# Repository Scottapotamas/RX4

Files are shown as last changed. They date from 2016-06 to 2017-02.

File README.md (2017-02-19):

# RX4
Four receiver diversity board for 5.8Ghz video. Features onboard regulator, buzzer, oled and more. Should fit in a compact form factor.

I need to get the software working properly. I've tried to leave the source available where possible, though I haven't documented much of this as its a personal project.

# Progress so far

Some enclosure concepts have been drawn up.

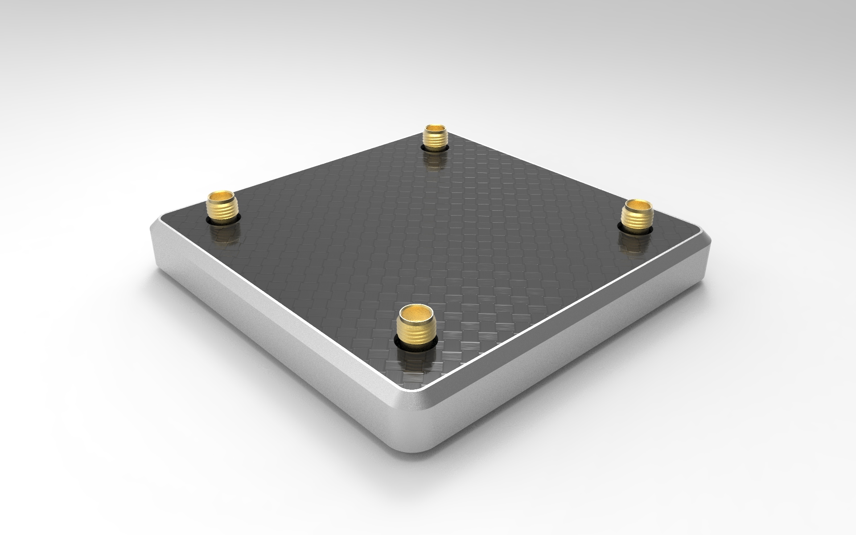
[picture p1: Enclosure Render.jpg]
Proposed Enclosure


The board has been made, and a basic level of validation done to show that everything works hardware wise.

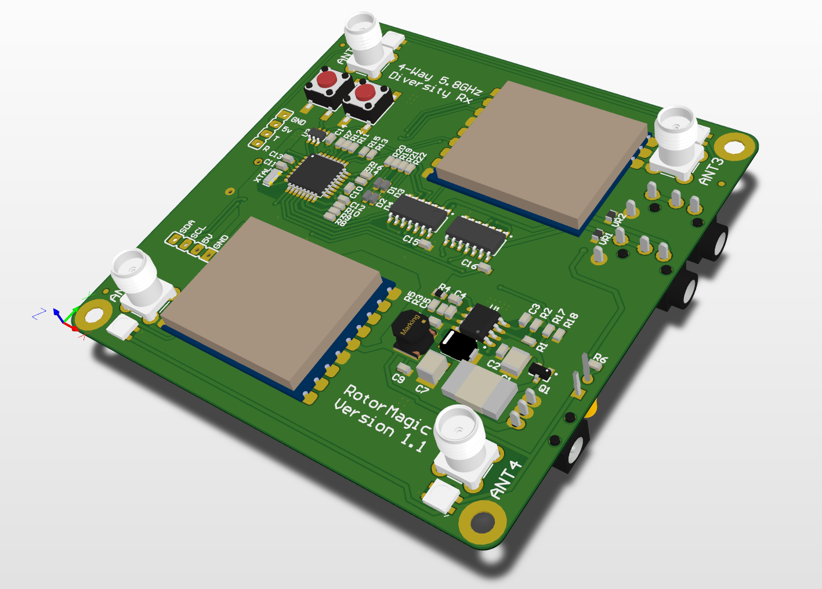
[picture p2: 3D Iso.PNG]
3D Iso View


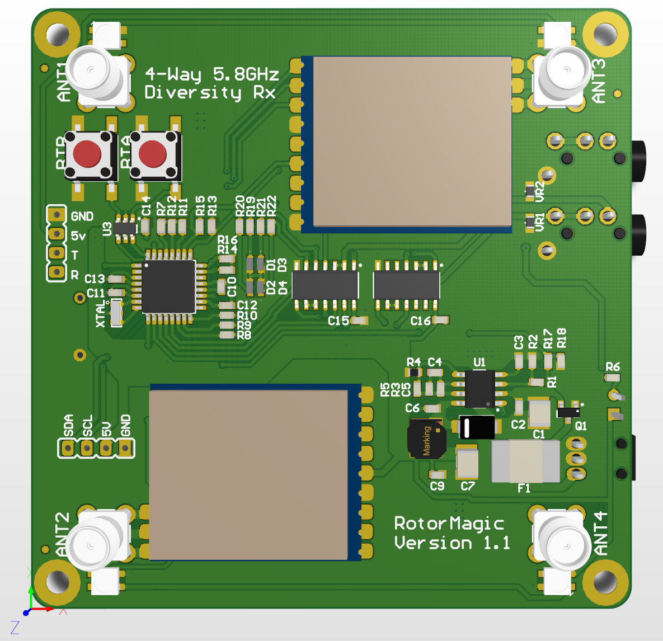
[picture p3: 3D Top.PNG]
3D Top View


The schematics and gerbers are all in this repo if anyone wants to borrow ideas for similar designs. There are other boards out there like the RX5800-Pro project and similar, but we use the TX5813 modules on this board due to native SPI support (no need to mod the 5800 internal resistors).

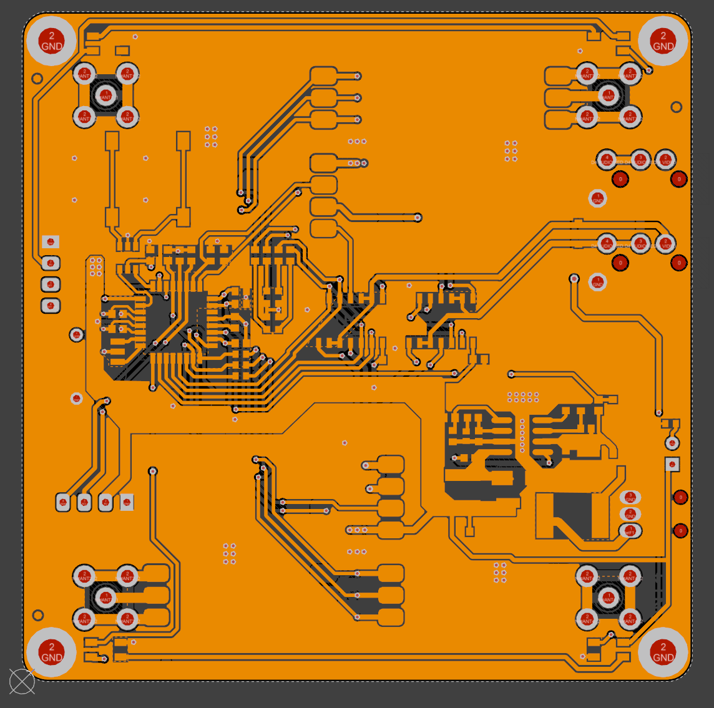
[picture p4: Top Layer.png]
Top Layer


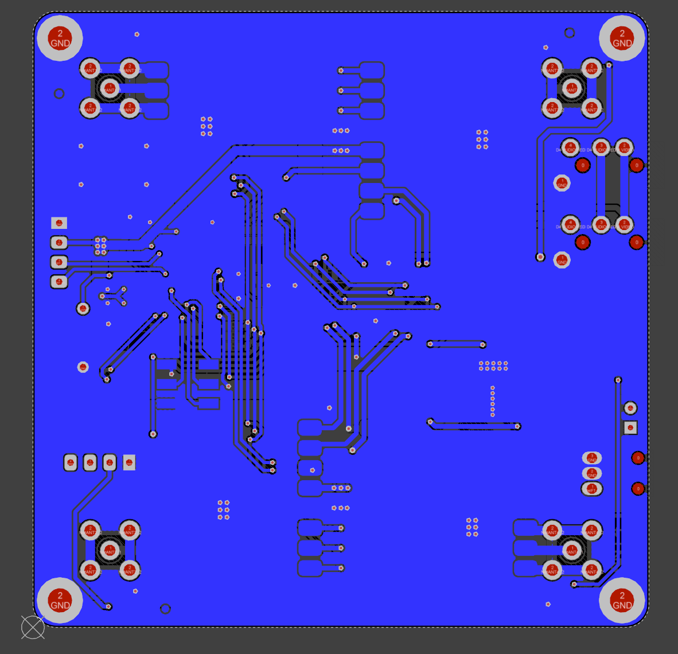
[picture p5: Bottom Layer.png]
Bottom Layer


The board is a simple 2-layer, 1oz design that fits inside a 80x80mm footprint. It should cost less than $40 to produce if you buy parts from Aliexpress/Banggood/Chinese sellers.

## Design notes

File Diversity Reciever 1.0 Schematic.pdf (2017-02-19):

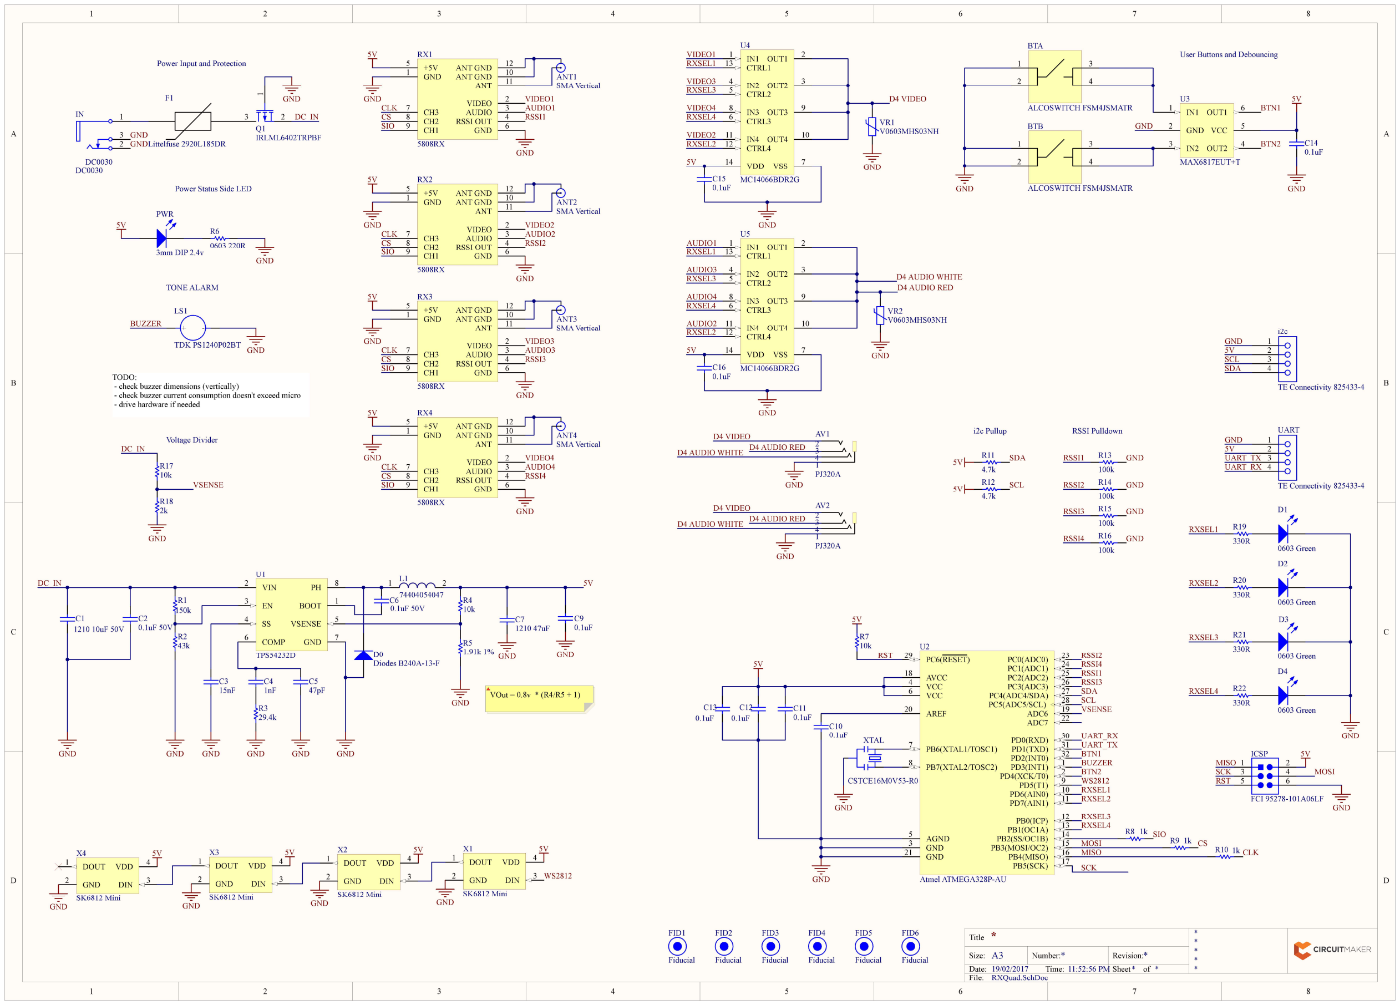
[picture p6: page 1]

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
* | *

*

* | *
19/02/2017 | 11:52:56 PM
RXQuad.SchDoc

Title

Size: | Number:
Date:
File:

Revision:
Time: | Sheet | of

A3

ANT1
SMA Vertical

ANT2
SMA Vertical

ANT3
SMA Vertical

ANT4
SMA Vertical

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
VIDEO1

VIDEO2

VIDEO3

VIDEO4

AUDIO1

AUDIO2

AUDIO3

AUDIO4

RSSI1

RSSI2

RSSI3

RSSI4

FID3

Fiducial

FID2

Fiducial

FID1

Fiducial

F1

Littelfuse 2920L185DR | 1
| 3 2 Q1 IRLML6402TRPBF

GND

DC_IN

1

2
3
4

AV1

PJ320A

1

2
3
4

AV2

PJ320A

GND

GND

D4 VIDEO

D4 VIDEO
D4 AUDIO RED

D4 AUDIO RED D4 AUDIO WHITE

D4 AUDIO WHITE

GND

GND

1

2

3

DC0030

IN

DC0030

PWR

3mm DIP 2.4v
GND
IN1 1 | OUT1 | 2
| OUT2 | 3

IN2 4
CTRL2 5

CTRL3 6

VSS | 7
IN3 8 | OUT3 | 9
OUT4 | 10 IN4 11
CTRL4 12

CTRL1 13

VDD 14

U4

MC14066BDR2G

IN1 1 | OUT1 | 2
| OUT2 | 3

IN2 4
CTRL2 5

CTRL3 6

VSS | 7
IN3 8 | OUT3 | 9
OUT4 | 10 IN4 11
CTRL4 12

CTRL1 13

VDD 14

U5

MC14066BDR2G

5V

5V

VIDEO1

VIDEO2

VIDEO4

AUDIO1

AUDIO3

AUDIO4

D4 VIDEO

D4 AUDIO RED

RXSEL1

RXSEL2

RXSEL4

RXSEL1

RXSEL2

RXSEL4

C16
0.1uF

GND

GND

VIDEO3

AUDIO2

RXSEL3

RXSEL3

+ -

LS1

TDK PS1240P02BT

PB5(SCK) 17

PB7(XTAL2/TOSC2) 8

PB6(XTAL1/TOSC1) 7

GND 3
GND 21

VCC 4
VCC 6

AGND 5

AREF 20

AVCC 18

PB4(MISO) | 16 PB3(MOSI/OC2) | 15 PB2(SS/OC1B) | 14 PB1(OC1A) | 13 PB0(ICP) | 12
PD7(AIN1) | 11 PD6(AIN0) | 10 PD5(T1) | 9
PD4(XCK/T0) | 2
PD3(INT1) | 1
PD2(INT0) | 32 PD1(TXD) | 31 PD0(RXD) | 30
ADC7 | 22 ADC6 | 19 PC5(ADC5/SCL) | 28 PC4(ADC4/SDA) | 27 PC3(ADC3) | 26 PC2(ADC2) | 25 PC1(ADC1) | 24 PC0(ADC0) | 23 PC6(RESET) 29

U2

Atmel ATMEGA328P-AU

RSSI1

RSSI2

RSSI3

RSSI4

R8 1k
R9 1k
R10 1k

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
4.7k
R12
4.7k

5V

5V

RSSI1

RSSI2

RSSI3

RSSI4

R13
100k
R14
100k
R15
100k
R16
100k

GND

GND

GND

GND

i2c Pullup | RSSI Pulldown

DC_IN

VSENSE

R17
10k

R18
2k

GND

Voltage Divider

VSENSE

UART_TX

UART_RX

RXSEL1
RXSEL2

RXSEL3
RXSEL4

BUZZER

TONE ALARM

5V

Power Status Side LED

Power Input and Protection

FID5

Fiducial

FID4

Fiducial

FID6

Fiducial

BTN1

BTN1

BTN2

XTAL

CSTCE16M0V53-R0

GND

IN1 1

GND 2

IN2 3 | OUT2

4

VCC

5

OUT1

6

U3

MAX6817EUT+T

5V

GND

C14
0.1uF
GND | GND

User Buttons and Debouncing

GND

TODO:
- check buzzer dimensions (vertically)
- check buzzer current consumption doesn't exceed micro
- drive hardware if needed

BUZZER

BTN2 | 3 1 2

6

4
5

ICSP

FCI 95278-101A06LF
GND

RST

SCK

MISO
MOSI

5V

RST

MISO

MOSI

SCK

R7
10k

5V

C10
0.1uF

GND

5V

BOOT 1

VIN 2

EN 3

SS 4 | VSENSE | 5
COMP 6 | GND | 7
| PH | 8

U1

TPS54232D

C2
0.1uF 50V

GND

R1
150k

C3
15nF

GND

C4
1nF

C5
47pF

R3
29.4k
GND | GND

C6
0.1uF 50V

GND

R4
10k

GND

GND | GND

D0
Diodes B240A-13-F

1 2 L1

74404054047

5V

D4 AUDIO WHITE

R6
0603 220R

DC_IN

C11
0.1uF

C12
0.1uF

VR1
V0603MHS03NH

VR2
V0603MHS03NH

GND

5V

WS2812

5V | 5V 5V

1
2
3
4

i2c

TE Connectivity 825433-4

1
2
3
4

UART

TE Connectivity 825433-4

GND
5V
UART_TX
UART_RX

GND
5V
SCL
SDA

C13
0.1uF

1 3

2 4

BTA

ALCOSWITCH FSM4JSMATR

1 3

2 4

BTB

ALCOSWITCH FSM4JSMATR

GND 1

VIDEO | 2
AUDIO | 3
RSSI OUT | 4

+5V 5

GND 6

CH3 7
CH2 8
CH1 9
ANT GND | 10
ANT | 11
ANT GND | 12

RX1

5808RX

GND 1

VIDEO | 2
AUDIO | 3
RSSI OUT | 4

+5V 5

GND 6

CH3 7
CH2 8
CH1 9
ANT GND | 10
ANT | 11
ANT GND | 12

RX2

5808RX

GND 1

VIDEO | 2
AUDIO | 3
RSSI OUT | 4

+5V 5

GND 6

CH3 7
CH2 8
CH1 9
ANT GND | 10
ANT | 11
ANT GND | 12

RX3

5808RX

GND 1

VIDEO | 2
AUDIO | 3
RSSI OUT | 4

+5V 5

GND 6

CH3 7
CH2 8
CH1 9
ANT GND | 10
ANT | 11
ANT GND | 12

RX4

5808RX
D1

0603 Green
D2

0603 Green

D3

0603 Green
D4

0603 Green

R19
330R

R20
330R

R21
330R

R22
330R

RXSEL1

RXSEL2

RXSEL3

RXSEL4

GND

C7
1210 47uF

C9
0.1uF

GND

R2
43k

C1
1210 10uF 50V
R5
1.91k 1%

WS2812

GND

C15
0.1uF
DIN | 3
VDD | 4 DOUT 1

GND 2

X1

SK6812 Mini

DIN | 3
VDD | 4 DOUT 1

GND 2

X2

SK6812 Mini

DIN | 3
VDD | 4 DOUT 1

GND 2

X3

SK6812 Mini

DIN | 3
VDD | 4 DOUT 1

GND 2

X4

SK6812 Mini
GND | GND | GND | GND

VOut = 0.8v * (R4/R5 + 1)

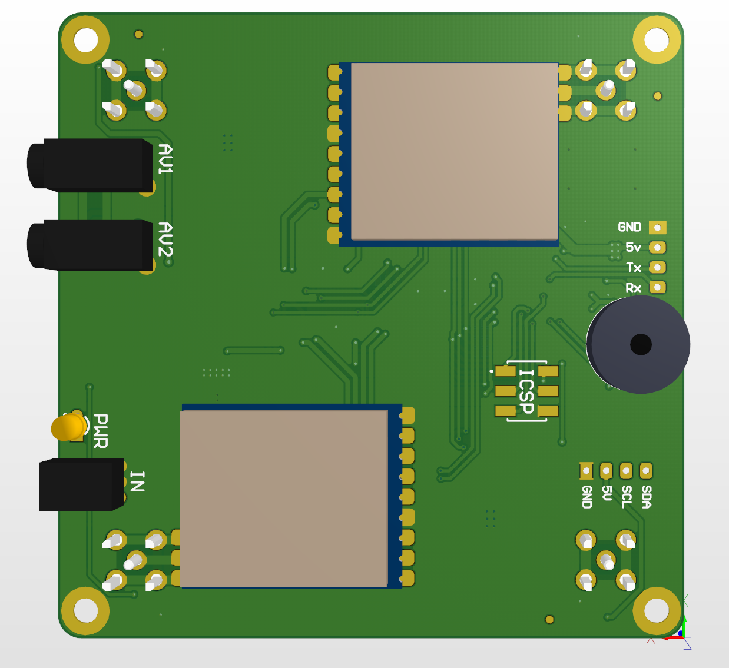
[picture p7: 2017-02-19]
3D Bottom.PNG

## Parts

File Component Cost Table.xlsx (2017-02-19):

 | 4 Way Diversity Board |  |  | Single Board Part Cost (in qty 10)
RS Item Number | QTY | Name | Description | Price | Summed Cost | Link | Link 2
616-3422 | 4 | SMA Vertical | SMA vertical, 4-pinG connector (J34 on ali) | 0.35 | 1.4 | http://www.aliexpress.com/item/Free-Shipping-10pcs-lot-PCB-Mount-SMA-Female-Plug-Straight-Receptacle-Solder-Adapter-Connector/1922491056.html | http://au.rs-online.com/web/p/sma-connectors/6163422/
703-1149 | 1 | 3mm White LED | Power Status LED | 0.1 | 0.1 | http://www.aliexpress.com/item/50pcs-3mm-Flat-Top-LED-LAMP-White-Super-brgiht-Wide-Angle-Light-Transparent-Light-Emitting-Diode/32618888645.html
732-6841 | 1 | MAX6817EUT | Switch Debouncer Circuit | 3.1 | 3.1 | http://www.aliexpress.com/item/Free-shipping-5pcs-lot-MAX6817EUT-MAX6817-interface-chip-SOT-23-6-new-original/32594672709.html
780-0712 | 1 | 12mm 5V buzzer | Warning Alert and Tones | 0.74 | 0.74 | http://www.aliexpress.com/item/Free-shipping-12x6-5-5V-buzzer-active-electromagnetic-YMD12065-10pcs/32302608810.html
479-1508 | 2 | 6x6x6 Tactile Button | Menu buttons | 0.15 | 0.3 | http://www.aliexpress.com/item/Free-shipping-10pcs-4pin-SMD-6-6-6mm-for-Tact-Switch-Push-Button-Tactile-Pushbutton-LCD/32374729164.html
 | 1 | WQP-DC0030 | 3.5x1.3mm DC Socket | 0.19 | 0.19 | http://www.aliexpress.com/item/10-Pcs-Black-3-Pin-3-5mm-x-1-3mm-DC-Power-Jack-Socket-PCB-Mount/32526176898.html | http://www.qingpu-electronics.com/en/products/WQP-DC0030-42.html
 | 2 | WQP-PJ320A | 3.5mm AV 4 pole socket | 0.22 | 0.44 | http://www.aliexpress.com/item/20PCS-LOT-PJ320A-pj320a-PJ-320A-pj-320a-100-New-Original-Package/32639808990.html | http://www.qingpu-electronics.com/en/products/WQP-PJ320A-175.html
 | 1 | 0.91" OLED | On pcb already, 128x32px | 5.4 | 5.4 | http://www.aliexpress.com/item/0-91-OLED-display-module-128-x-32-px-resolution-white-characters-in-black-background-14/32629988003.html
 | 4 | RX5808 Module | 5.8Ghz module | 12 | 48 | http://www.aliexpress.com/item/FPV-Boscam-FPV-5-8G-Wireless-Audio-Video-Receiving-Module-RX5808-free-shipping/32557296513.html | http://www.banggood.com/FPV-5_8G-Wireless-Audio-Video-Receiving-Module-RX5808-p-84775.html
169-7790 | 2 | 74HC4066D SOIC14 | 4x SPST digital switch | 0.71 | 1.42 | http://au.rs-online.com/web/p/products/1697790/
760-6826 | 4 | V0603MHS03NH | MOV/Varistor 6pF 1A 135V 0603 | 0.33 | 1.32 | https://au.rs-online.com/web/p/products/7606826/?sra=p&r=t#
619-7740 | 1 | NCP18XH103J03RB | 10k 0603 Thermistor | 0.1 | 0.1 | http://www.aliexpress.com/item/Free-Shipping-50PCS-LOT-0603-SMD-Thermistor-Thermal-Resistor-5-10K-B-Value-3450K-3-25/32390676031.html | http://au.rs-online.com/web/p/thermistors/6197740/?searchTerm=0603+10k+thermistor
696-3092 | 1 | ATMEGA328P-AU | Microcontroller | 5.61 | 5.61 | http://au.rs-online.com/web/p/products/6963092/
700-9975 | 1 | B240A | Power Supply Diode | 0.32 | 0.32 | http://au.rs-online.com/web/p/products/7009975/?sra=p&r=t
792-6524 | 1 | CSTCE16M0V53-R0 | 16Mhz Resonator | 0.336 | 0.336 | http://au.rs-online.com/web/p/ceramic-resonators/7926524/
301-322 | 1 | IRLML6402TRPBF | P-Fet as ideal diode | 0.75 | 0.75 | http://au.rs-online.com/web/p/mosfet-transistors/0301322/
895-1640 | 1 | 2920L200DR | 2A Polyfuse | 1.03 | 1.03 | http://au.rs-online.com/web/p/resettable-surface-mount-fuses/8951640/
 | 4 | SK6812 MINI | RGB LEDs for status lights | 0.55 | 2.2 | https://www.adafruit.com/products/2659 | http://www.aliexpress.com/item/SMD3535-Beads-smart-led-mini-led-SK6812MINI-SK6812-adressable-full-color-RGB-3535-LED-light-source/32425415556.html
698-9085 | 1 | TPS54232D | SMPS regulator | 2.91 | 2.91 | http://au.rs-online.com/web/p/buck-converters/6989085/?searchTerm=TPS54232D
814-2559 | 1 | 74404054047 | 4.7uH 3A Inductor | 1 | 1 | http://au.rs-online.com/web/p/wire-wound-surface-mount-inductors/8142559/
 | 14 | 0603 Capacitors | Assorted, Ceramic, X7R | 0.05 | 0.7
 | 19 | 0603 Resistors | Assorted, 5%, 1/8W | 0.01 | 0.19
MTO | 1 | PCB 80x80mm | 2 layer, 1oz | 2 | 2 | http://www.elecrow.com/10pcs-2-layer-pcb-p-1175.html
 |  |  |  | Total Cost | 79.556

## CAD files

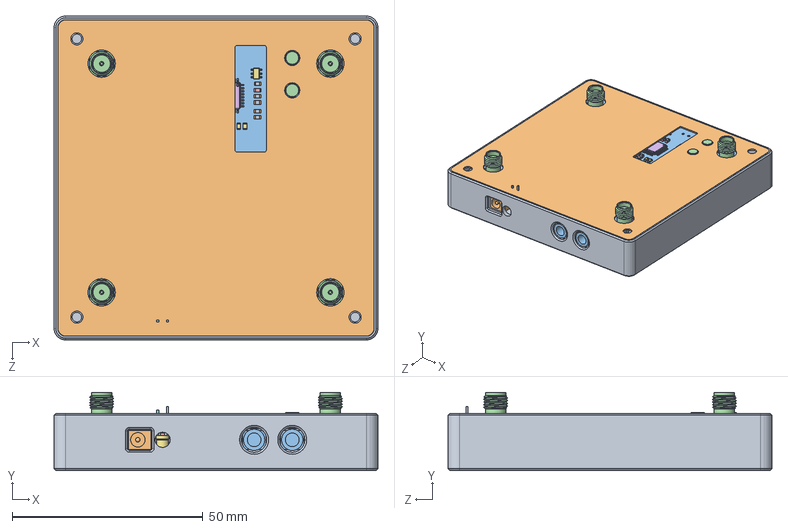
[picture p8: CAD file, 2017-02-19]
CAD/Enclosure Mockup/Prototype Enclosure 1.SLDASM
85.0 x 20.5 x 85.0 mm
Alu enclosure
Lid
Board
Extruded x 3
Extruded_2 x 6
V0603MHS03NH_Varistor x 4
Extruded_3
Extruded_4
Extruded_5 x 4
Extruded_6 x 8
Extruded_7 x 4
Extruded_8 x 8
User_Library-LA_3366_sc_BODY_amber
User_Library-LA_3366_sc_LEAD_A_sc
User_Library-LA_3366_sc_LEAD_K_sc
DC0030
PJ320A x 2
c-5-1814832-1-b-3d x 4
RX5808 x 4
Extruded_9 x 2
Extruded_10
User_Library-SOT23-3
Extruded_11 x 8
Extruded_12 x 4
Extruded_13 x 8
Extruded_14 x 4
Diode_SMA
S2B-PH-K-S
housing
contact x 2
spule
Glue
Extruded_15
Extruded_16 x 2
Extruded_17 x 3
Extruded_18 x 6
Extruded_19 x 6
Extruded_20 x 12
Extruded_21 x 5
Extruded_22 x 10
Extruded_23
Extruded_24 x 2
TQFP32-08
BODY_MF06A
LEAD_MF06A x 6
BODY_M14A_20 x 2
LEAD_M14A_46 x 28
SK6812Mini x 4
X3-SMD-3.6X1.3X0.8MM

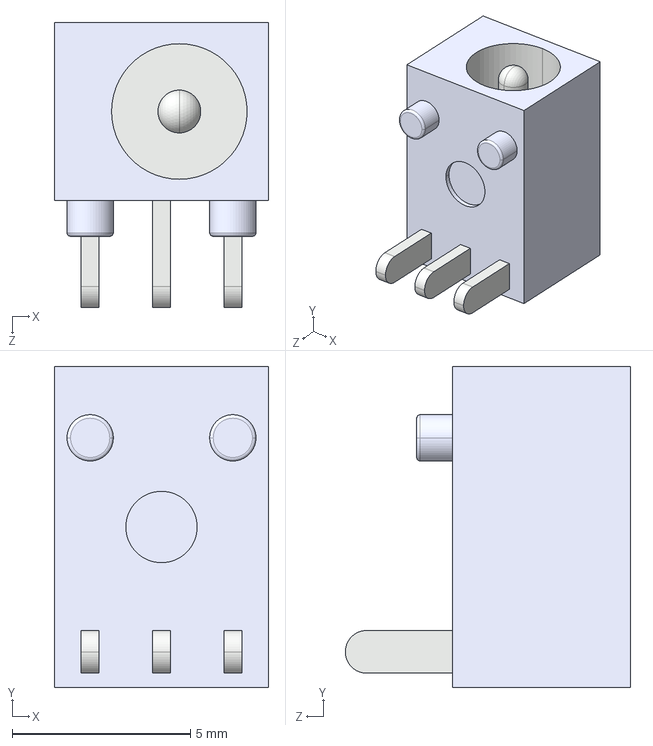
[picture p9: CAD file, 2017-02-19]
CAD/Connectors/DC0030.STEP
6.00 x 9.00 x 8.00 mm

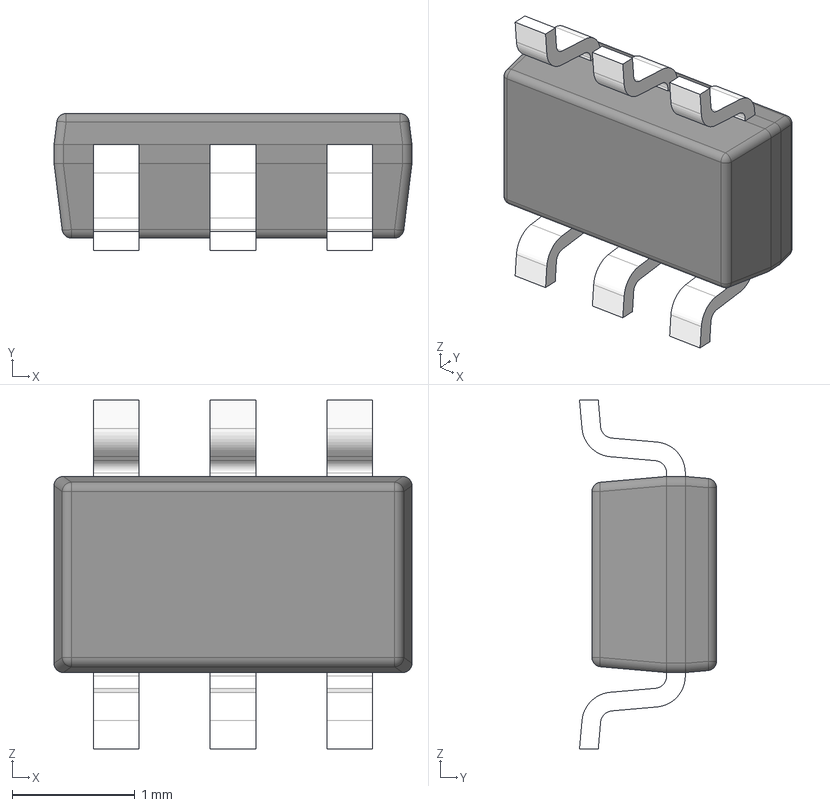
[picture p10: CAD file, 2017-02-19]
CAD/ICs/sot-23-6.stp
2.92 x 1.12 x 2.84 mm
BODY_MF06A
LEAD_MF06A x 6

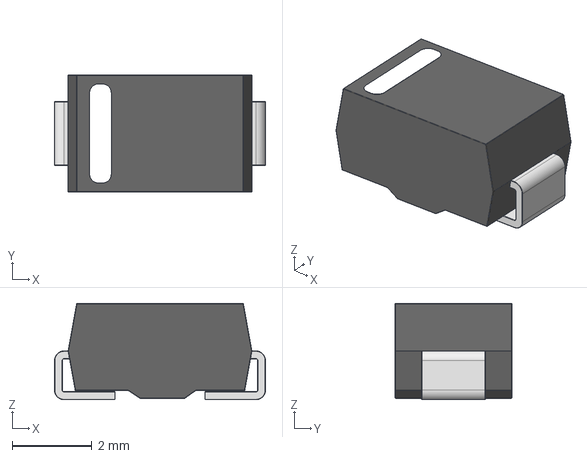
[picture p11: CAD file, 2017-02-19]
CAD/Other/Diode SMA.stp
5.28 x 2.92 x 2.41 mm

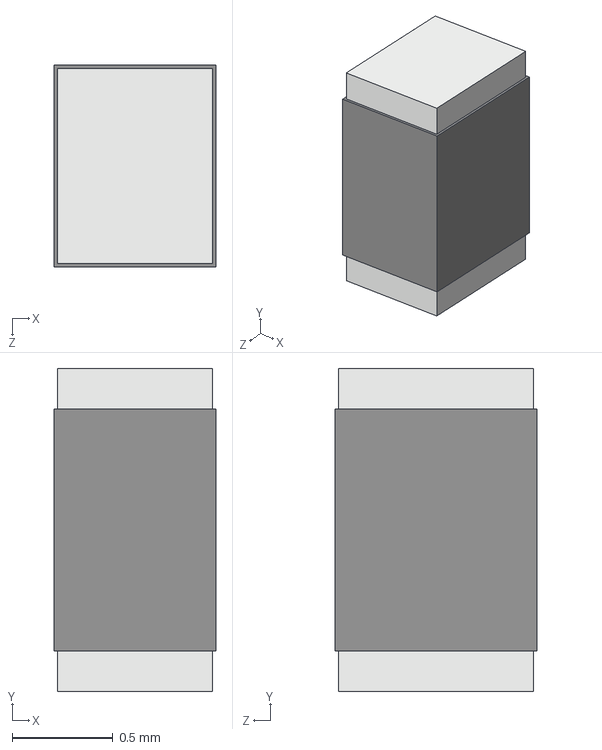
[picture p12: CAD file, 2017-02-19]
CAD/Passives/V0603MHS03NH Varistor.STEP
0.8 x 1.60 x 1.00 mm

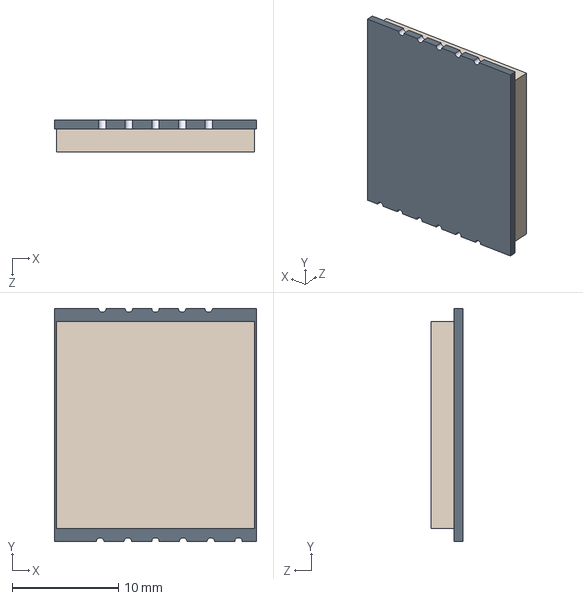
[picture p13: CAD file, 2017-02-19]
CAD/RF Module Models/TX5813.STEP
19.0 x 21.9 x 3.00 mm

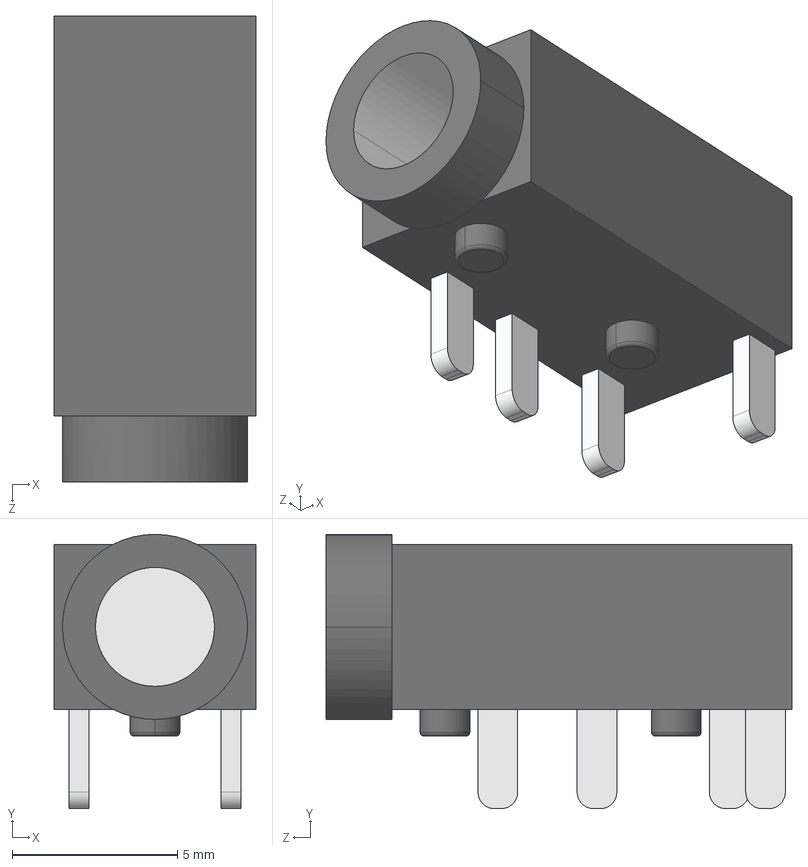
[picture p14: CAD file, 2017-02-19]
CAD/Connectors/PJ320A.STEP
6.10 x 8.30 x 14.1 mm

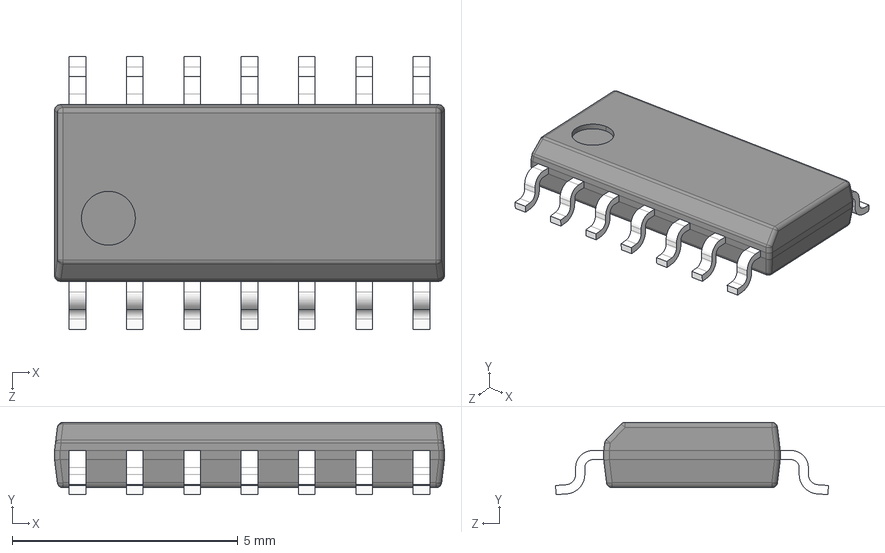
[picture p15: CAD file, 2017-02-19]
CAD/ICs/soic-14.STEP
8.64 x 1.60 x 6.05 mm
BODY_M14A_20
LEAD_M14A_46 x 14

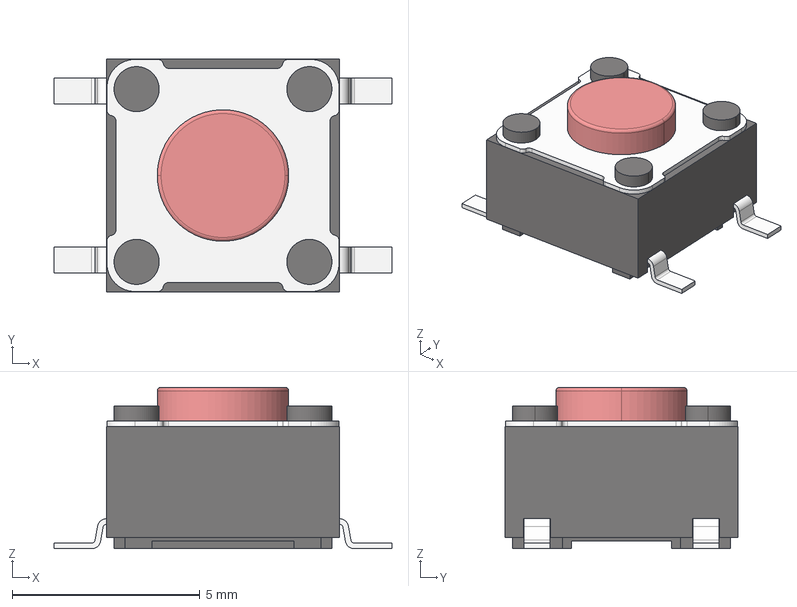
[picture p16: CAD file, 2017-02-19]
CAD/Other/Tact Switch SMD 6x6mm.stp
9.00 x 6.20 x 4.30 mm

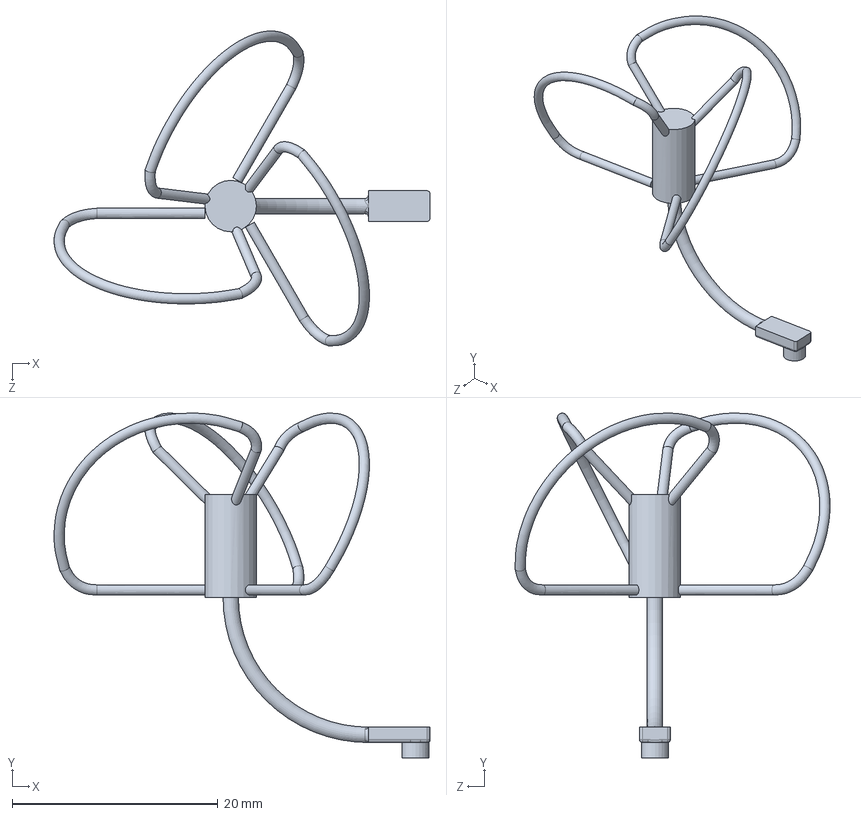
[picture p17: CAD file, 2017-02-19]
CAD/RF Module Models/antenna.SLDPRT
36.5 x 33.5 x 30.6 mm

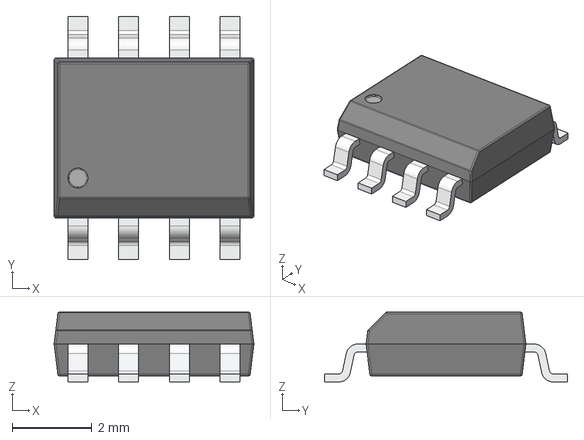
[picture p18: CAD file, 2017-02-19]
CAD/ICs/SOIC-8.stp
5.00 x 6.08 x 1.75 mm

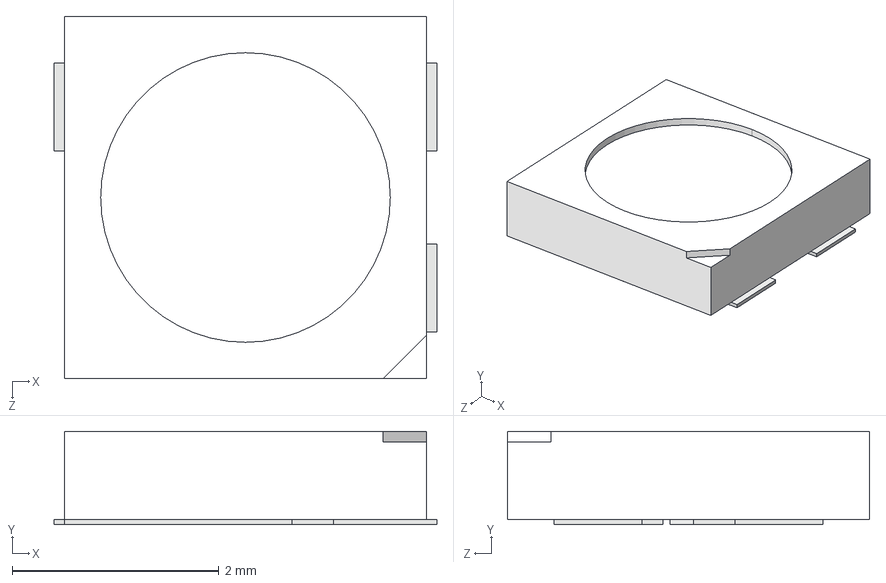
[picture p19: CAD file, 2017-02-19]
CAD/Other/SK6812Mini.STEP
3.70 x 0.9 x 3.50 mm

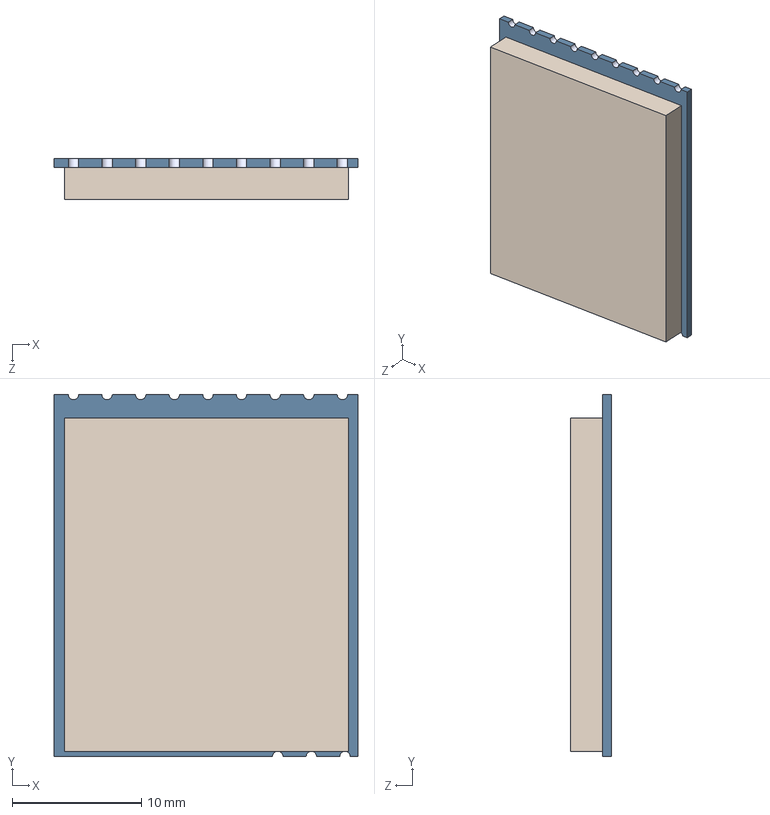
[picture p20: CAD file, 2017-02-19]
CAD/RF Module Models/RX5808.STEP
23.5 x 28.0 x 3.20 mm

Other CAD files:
CAD/Enclosure Mockup/Extruded_23.sldprt
CAD/Enclosure Mockup/Extruded_21.sldprt
CAD/Enclosure Mockup/Extruded_12.sldprt
CAD/Enclosure Mockup/COMPOUND_2.sldprt
CAD/Enclosure Mockup/User_Library-LA_3366_sc_LEAD_K_sc.sldprt
CAD/Connectors/DC0030.SLDPRT
CAD/Connectors/PJ320A.SLDPRT
CAD/Enclosure Mockup/Alu enclosure.SLDPRT
CAD/Enclosure Mockup/BODY_M14A_20.sldprt
CAD/Enclosure Mockup/BODY_MF06A.sldprt
CAD/Enclosure Mockup/Board.sldprt
CAD/Enclosure Mockup/COMPOUND.sldprt
CAD/Enclosure Mockup/DC0030.sldprt
CAD/Enclosure Mockup/Diode_SMA.sldprt
CAD/Enclosure Mockup/Extruded.sldprt
CAD/Enclosure Mockup/Extruded_10.sldprt
CAD/Enclosure Mockup/Extruded_11.sldprt
CAD/Enclosure Mockup/Extruded_13.sldprt
CAD/Enclosure Mockup/Extruded_14.sldprt
CAD/Enclosure Mockup/Extruded_15.sldprt
CAD/Enclosure Mockup/Extruded_16.sldprt
CAD/Enclosure Mockup/Extruded_17.sldprt
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

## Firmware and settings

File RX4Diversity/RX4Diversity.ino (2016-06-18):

#include "U8glib.h"			//display driver and graphics
#include "FastLED.h"		//WS2812/SK6812 driver
#include <avr/pgmspace.h>	//pull values out of flash (LUTs etc)
#include <EEPROM.h>			//settings storage

// Settings and such
#define VERSION_NUMBER 1.0
#define RX_TYPE 1			//0 = RX5808, 1 = RX158
#define MODULE_COUNT 4		//number of RX modules

// Pinout mapping
#define VOLTAGE_SENSE A6	//ADC6, 19
#define BUZZER 3			//PD3, 01
#define BTN_1 2				//PD2, 32
#define BTN_2 4				//PD4, 02

#define WS2812_DATA  5		//PB5, 17
#define WS2812_COUNT 4		//led count might be different from rx count

#define SPI_DIO 10			//PB2, 14
#define SPI_CS  11			//PB3, 15
#define SPI_CLK 12			//PB4, 1
// #define UART_RX 0 //PD0, 12
// #define UART_TX 1 //PD1, 31
// #define I2C_SDA A4  //PC4, 27
// #define I2C_SCL A5  //PC5, 28

#define BATTERY_MAX 4.2
#define BATTERY_MIN 3.4
#define BATTERY_WARN 3.7

const int RX_RSSI_PIN[MODULE_COUNT] = {A2, A0, A3, A1};
const int RX_SEL_PIN[MODULE_COUNT] = {6, 7, 8, 9};
// #define RSSI1 A2  //PC2, 25
// #define RSSI2 A0  //PC0, 23
// #define RSSI3 A3  //PC3, 26
// #define RSSI4 A1  //PC1, 24
//#define RXSEL1  6 //PD6, 10
//#define RXSEL2  7 //PD7, 11
//#define RXSEL3  8 //PB0, 12
//#define RXSEL4  9 //PB1, 13


// Driver Object Definitions
CRGB leds[WS2812_COUNT];
U8GLIB_SSD1306_128X32 u8g(U8G_I2C_OPT_NONE);	// I2C / TWI 

// Defines
int button1, button2 = 0;
float input_voltage = 0;
int cell_count, batt_percentage = 0;

volatile int rx_rssi[MODULE_COUNT] = {0, 0, 0, 0};
int active_module = 0;
int active_freq = 0;
int active_band = 0;

int menu_State = 0;
int state_timeout = 0;

// Channels to sent to the SPI registers
const uint16_t channelTable[] PROGMEM = {
  // Channel 1 - 8
  0x2A05,    0x299B,    0x2991,    0x2987,    0x291D,    0x2913,    0x2909,    0x289F,    // Band A
  0x2903,    0x290C,    0x2916,    0x291F,    0x2989,    0x2992,    0x299C,    0x2A05,    // Band B
  0x2895,    0x288B,    0x2881,    0x2817,    0x2A0F,    0x2A19,    0x2A83,    0x2A8D,    // Band E
  0x2906,    0x2910,    0x291A,    0x2984,    0x298E,    0x2998,    0x2A02,    0x2A0C,    // Band F / Airwave
  0x281D,    0x288F,    0x2902,    0x2914,    0x2978,    0x2999,    0x2A0C,    0x2A1E     // Band C / Immersion Raceband
};

// Channels with their Mhz Values
const uint16_t channelFreqTable[] PROGMEM = {
  // Channel 1 - 8
  5865, 5845, 5825, 5805, 5785, 5765, 5745, 5725, // Band A
  5733, 5752, 5771, 5790, 5809, 5828, 5847, 5866, // Band B
  5705, 5685, 5665, 5645, 5885, 5905, 5925, 5945, // Band E
  5740, 5760, 5780, 5800, 5820, 5840, 5860, 5880, // Band F / Airwave
  5658, 5695, 5732, 5769, 5806, 5843, 5880, 5917  // Band C / Immersion Raceband
};

const char* bandNameTable[] = {
  "Boscam A", // Band A
  "Boscam B", // Band B
  "DJI / E", // Band E
  "Immersion", // Band F / Airwave
  "RaceBand", // Band C / Immersion Raceband
};

// All Channels of the above List ordered by Mhz
const uint8_t channelList[] PROGMEM = {
  19, 18, 32, 17, 33, 16, 7, 34, 8, 24, 6, 9, 25, 5, 35, 10, 26, 4, 11, 27, 3, 36, 12, 28, 2, 13, 29, 37, 1, 14, 30, 0, 15, 31, 38, 20, 21, 39, 22, 23
};


void setup_pins()
{
	sm_setup_pinMode();
	rx_setup_pinMode();

	pinMode(SPI_CLK, OUTPUT);
	pinMode(SPI_CS, OUTPUT);
	pinMode(SPI_DIO, OUTPUT);

	pinMode(BTN_1, INPUT);
	pinMode(BTN_2, INPUT);
	pinMode(VOLTAGE_SENSE, INPUT);
	pinMode(BUZZER, OUTPUT);
	pinMode(WS2812_DATA, OUTPUT);
}

void setup_peripherals()
{
	//i2c display init
	// u8g.setRot180();	//flip if needed

	// assign default color value
	if ( u8g.getMode() == U8G_MODE_R3G3B2 ) {
		u8g.setColorIndex(255);	// white
	}
	else if ( u8g.getMode() == U8G_MODE_GRAY2BIT ) {
		u8g.setColorIndex(3);	// max intensity
	}
	else if ( u8g.getMode() == U8G_MODE_BW ) {
		u8g.setColorIndex(1);	// pixel on
	}
	else if ( u8g.getMode() == U8G_MODE_HICOLOR ) {
		u8g.setHiColorByRGB(255,255,255);
	}

	//WS2812/SK6812 LED Setup
	// FastLED.addLeds<WS2812B, WS2812_DATA, GRB>(leds, WS2812_COUNT);
	// FastLED.setBrightness(0);
	// FastLED.show();
	//rx module init


}

void setup() 
{
	Serial.begin(115200);
	Serial.println("setup: entry");

	setup_pins();
	setup_peripherals();
	alert_startup();
	sm_set_active(1);

}

void loop()
{
	button1 = digitalRead(BTN_1);
	button2 = digitalRead(BTN_2);

	rx_sample_rssi();

	if(button1 == 0)
	{
		if(active_module >= MODULE_COUNT)
		{
			sm_set_active(1);
		} 
		else
		{
			sm_set_active(active_module+1);
		}
		delay(100);
	}

	if(button2 == 0)
	{
		Serial.print("Bt1:"); Serial.print(button1); Serial.print(" Bt2:");Serial.println(button2);
		rx_set_freq(active_freq+1);

		if(active_freq > 7)
		{
			rx_set_band(active_band+1);

			if(active_band > 4)
			{
				active_band = 0;
			}

			active_freq = 0;
		}

		delay(100);
		Serial.print("Band:"); Serial.print(active_band); Serial.print(" chSet:");Serial.println(active_freq);
		rx_push_data(rx_calculate_channel());
	}



	measure_battery();


	// picture loop
	u8g.firstPage();  
	do {
		draw();
	} while( u8g.nextPage() );
	
	// FastLED.setBrightness(0);
	// FastLED.show();
}

void test_cycle()
{
	if(active_module < 4)
	{
		sm_set_active(active_module+1);
	}
	else
	{
		sm_set_active(1);
	}

	for(int i = 0; i < 40; i++)
	{
		rx_push_data(i);
		delay(500);
		rx_sample_rssi();
		Serial.print("Ch"); Serial.print(i);  

		for(int j = 0; j < MODULE_COUNT; j++)
		{
			Serial.print(", "); Serial.print(rx_rssi[j]);	
		}
		Serial.println("");
	}

	Serial.println("\n\n");
}
//------- Display Handling --------

void draw(void) {
  // graphic commands to redraw the complete screen should be placed here  
  u8g.setFontPosTop();
  u8g.setFont(u8g_font_unifont); 

  ui_manager();
}

void ui_manager()
{
	switch(menu_State)
	{
		case 0:
			draw_splash();

			if(state_timeout > 100)
			{
				menu_State++;
				state_timeout = 0;
			}
			else
			{
				state_timeout++;
			}
			
		break;

		case 1:
			draw_mainpage();
		break;

		case 2:
			draw_settingslist();
		break;

		default:
			draw_error();
		break;
	}
} 

void draw_splash()
{
	u8g.setFont(u8g_font_helvR10r);
	u8g.drawStr( 12, 15, "ROTORMAGIC");

	u8g.setFont(u8g_font_helvR08r);
	u8g.drawStr( 8, 28, "4-Way Diversity RX 0.1");
	//TODO - Take version number from define
}

void draw_mainpage()
{
	char buf[10];

	//selected frequency
	sprintf(buf, "%d", pgm_read_word_near(channelFreqTable + (active_band*8 + active_freq)) );
	u8g.setFont(u8g_font_helvR14r);
	u8g.drawStr( 10, 15, buf);

	//Human readable band/ch selected
	u8g.setFont(u8g_font_helvR08r);
	sprintf(buf, "%s %d", bandNameTable[active_band], active_freq+1);
	u8g.drawStr( 0, 28, buf);

	
	//print battery stats
	sprintf (buf, "%dS %02d%%", cell_count, batt_percentage);
	u8g.drawStr( 85, 10, buf);


	sprintf (buf, "%d %d", rx_rssi[2-1], rx_rssi[1-1]);
	u8g.drawStr( 85, 20, buf);

	sprintf (buf, "%d %d", rx_rssi[4-1], rx_rssi[3-1]);
	u8g.drawStr( 85, 30, buf);

	//sprintf (buf, "%d %d", button1, button2);
	//u8g.drawStr( 98, 30, buf);
}

void draw_settingslist()
{
	u8g.setFont(u8g_font_helvR10r);
	u8g.drawStr( 12, 15, "Settings Menu");

	u8g.setFont(u8g_font_helvR08r);
	u8g.drawStr( 6, 28, "To be completed");
}

void draw_error()
{
	u8g.setFont(u8g_font_helvR10r);
	u8g.drawStr( 12, 15, "MENU ERROR");

	u8g.setFont(u8g_font_helvR08r);
	u8g.drawStr( 6, 28, "Something went wrong :(");
}
}
//------- Battery Handling ---------
void measure_battery()
{
	float adc_Voltage = (analogRead(VOLTAGE_SENSE) / 1024) * 5.0;
	//adc reads 10bit, 0-5v range
	//10k and 2k divider gives 4.67v max adc for 28V input = 0.167x
	input_voltage = adc_Voltage / 0.167;
}

void determine_cell_count()
{
	//how the fuck do we do this reliably?
	cell_count = (input_voltage / BATTERY_MAX) + 1;

	if(cell_count > 6)
	{
		//TODO - handle over cell count detection or stupid user

	}

	if(cell_count < 2)
	{
		//TODO - handle 1S detected, or no valid reading

	}
}

void calculate_battery_percentage()
{
	batt_percentage = ((input_voltage - (BATTERY_MIN * cell_count)) * 100) / ((BATTERY_MAX - BATTERY_MIN) * cell_count);
}

void check_battery_health()
{
	if(input_voltage < (BATTERY_WARN * cell_count))
	{
		//TODO - handle low battery alarm

	}
	else if(input_voltage < (BATTERY_MIN * cell_count))
	{
		//TODO - handle flat/urgent battery alarm

	}
	else 	
	{
		//battery is sufficiently full, should probably schedule the next check or something

	}
}

//---------- RX Functions ----------
void rx_setup_pinMode()
{
	for(int i = 0; i < MODULE_COUNT; i++)
	{
		pinMode(RX_RSSI_PIN[i], INPUT);
	}
}

void rx_set_freq(int freqNum)
{
	active_freq = constrain(freqNum, 0, 8);
}

void rx_set_band(int bandNum)
{
	active_band = constrain(bandNum, 0, 5);
}

int rx_calculate_channel() {
	Serial.print("Calculated ch"); 	Serial.println(active_band*8 + active_freq);
	return active_band*8 + active_freq;
}

void rx_sample_rssi()
{
	for(int i = 0; i < MODULE_COUNT; i++)
	{
		rx_rssi[i] = analogRead(RX_RSSI_PIN[i]);
	}
}

void rx_decide_active()
{

}

void rx_calibration()
{

}

void rx_autoscan()
{

}

void rx_push_data(uint8_t channel)
{
  uint8_t i;
  uint16_t channelData;

  channelData = pgm_read_word_near(channelTable + channel);

  // bit bang  25 bits of data
  // Order: A0-3, !R/W, D0-D19
  // A0=0, A1=0, A2=0, A3=1, RW=0, D0-19=0
  rx_enable_high();
  delayMicroseconds(1);
  //delay(2);
  rx_enable_low();

  rx_send_bit0();
  rx_send_bit0();
  rx_send_bit0();
  rx_send_bit1();

  rx_send_bit0();

  // remaining zeros
  for (i = 20; i > 0; i--)
  {
    rx_send_bit0();
  }

  // Clock the data in
  rx_enable_high();
  //delay(2);
  delayMicroseconds(1);
  rx_enable_low();

  // Second is the channel data from the lookup table
  // 20 bytes of register data are sent, but the MSB 4 bits are zeros
  // register address = 0x1, write, data0-15=channelData data15-19=0x0
  rx_enable_high();
  rx_enable_low();

  // Register 0x1
  rx_send_bit1();
  rx_send_bit0();
  rx_send_bit0();
  rx_send_bit0();

  // Write to register
  rx_send_bit1();

  // D0-D15
  //   note: loop runs backwards as more efficent on AVR
  for (i = 16; i > 0; i--)
  {
    // Is bit high or low?
    if (channelData & 0x1)
    {
      rx_send_bit1();
    }
    else
    {
      rx_send_bit0();
    }

    // Shift bits along to check the next one
    channelData >>= 1;
  }

  // Remaining D16-D19
  for (i = 4; i > 0; i--)
  {
    rx_send_bit0();
  }
  // Finished clocking data in
  rx_enable_high();
  delayMicroseconds(1);
  //delay(2);

  digitalWrite(SPI_CS, LOW);
  digitalWrite(SPI_CLK, LOW);
  digitalWrite(SPI_DIO, LOW);
}

void rx_send_bit1()
{
  digitalWrite(SPI_CLK, LOW);
  delayMicroseconds(1);

  digitalWrite(SPI_DIO, HIGH);
  delayMicroseconds(1);
  digitalWrite(SPI_CLK, HIGH);
  delayMicroseconds(1);

  digitalWrite(SPI_CLK, LOW);
  delayMicroseconds(1);
}

void rx_send_bit0()
{
  digitalWrite(SPI_CLK, LOW);
  delayMicroseconds(1);

  digitalWrite(SPI_DIO, LOW);
  delayMicroseconds(1);
  digitalWrite(SPI_CLK, HIGH);
  delayMicroseconds(1);

  digitalWrite(SPI_CLK, LOW);
  delayMicroseconds(1);
}

void rx_enable_high()
{
  delayMicroseconds(1);
  digitalWrite(SPI_CS, HIGH);
  delayMicroseconds(1);
}

void rx_enable_low()
{
  delayMicroseconds(1);
  digitalWrite(SPI_CS, LOW);
  delayMicroseconds(1);
}

//------- Switching Matrix --------
void sm_setup_pinMode()
{
	for(int i = 0; i < MODULE_COUNT; i++)
	{
		pinMode(RX_SEL_PIN[i], OUTPUT);
	}
}

// Sets the 4 pins for the digital switches to route selected module to the output.
void sm_set_active(int moduleRequested)
{
	if(moduleRequested == 0)
	{
		alert_debug("sm mR0");
		sm_set_active(1);	//always default to something
	}

	for(int i = 0; i < MODULE_COUNT; i++)
	{
		if(i == moduleRequested-1)
		{
			digitalWrite(RX_SEL_PIN[i],HIGH);
			active_module = moduleRequested;	//only write values here, everywhere else should RO
		}
		else
		{
			digitalWrite(RX_SEL_PIN[i],LOW);
		}
	}
}

//------------- Alerts -------------
void alert_startup()
{
	status_setup();
	buzz_startup();
}

void alert_low_battery() 
{
	buzz_battery_low();
}

void alert_critical_battery() 
{
	buzz_battery_critical();
}

void alert_low_signal()
{

}

void alert_rx_error()
{

}

void alert_channel_change()
{
	buzz_freq_change();
}

void alert_band_change()
{
	buzz_band_change();
}

void alert_debug(String debugText)
{
	Serial.println(debugText);
	buzz_alert();
}

//---------- LED Outputs ----------

void status_setup()
{
	// int col = 0;

	// for(int i = 0; i < 254; i++)
	// {
	// 	for(int j = 0; j < strip.numPixels(); j++) {
	//     	strip.setPixelColor(j, strip.Color(col,col,col));
	//     	col++;
 //  		}
 //  		strip.show();
 //  		delay(10);
	// }

	// strip.clear();
	// strip.show();
}

void status_autoscan()
{

}

void status_dominant_rx()
{
	for(int i = 0; i < WS2812_COUNT; i++) {

		if(active_module-1 == i)
		{
			leds[i] = CRGB::Red;
		}
		else
		{
			leds[i] = CRGB::Black; //.fadeToBlackBy(128);
		}

	}

}

void status_low_battery()
{

}

void status_setting_save() 
{

}

//led solid for module led
void status_channel_change()
{

}

//flash all leds with colour code for band
void status_band_change()
{

}


//--------- Buzzer -----------

void buzz_tone(int note, int duration)
{
	tone(BUZZER,note,duration); 
}

void buzz_alert()
{
	buzz_tone(280, 40);
	delay(40);
	buzz_tone(280, 40);
}

void buzz_band_change()
{
	buzz_tone(650, 40);

}

void buzz_freq_change()
{
	buzz_tone(440, 80);

}

void buzz_module_change()
{
	buzz_tone(1250, 15);
}

void buzz_battery_low()
{
	buzz_tone(200, 50);
	delay(40);
	buzz_tone(350, 50);
}

void buzz_battery_critical()
{
	buzz_tone(350, 50);
	delay(40);
	buzz_tone(350, 50);
	delay(40);
	buzz_tone(350, 50);
}

void buzz_startup()
{
	buzz_tone(440, 100);
	delay(150);
	buzz_tone(860, 100);
	delay(150);
	buzz_tone(1280, 140);
}

//-------- Setting Save --------

void memory_check_first_run()
{

}

void memory_read_settings()
{

}

void memory_pull_settings()
{

}

void memory_push_settings()
{

}






/*

TODO

split codebase into files per topic
move pinout arrays into progmem

LED handling code
	remap leds to correct order on board
	startup animation
	channel indication led (in band colour)
	band indication flash (in band colour)
	fading between states/hues
	error animation
	low battery animation
	rssi visualisation mode (rainbow hues for each led)

Buzzer code
	complex tone generation

Menu System
	Settings Menu
	Overlay alert screens

General functions
	Calibration function
	module selection logic
	button handling
	non-blocking timers
	timer based callbacks

EEPROM
	Save/recall functions
	Channel and band settings
	Store calibration data
	store user settings

Create startup tutorial
*/

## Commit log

2016-06-17 Brought project into git. Just implemented early stage FastLED to remove ada library
2016-06-17 FastLED now replaces Adafruit neopixel library
    [RX4Diversity.ino]
2016-06-17 Added some display code - hacked in, needs cleanup Added battery monitoring functions rough cut
2016-06-17 More battery handling code
2016-06-17 Fixed copy error in iterative pinmode setup
    [RX4Diversity.ino]
2016-06-17 Led code additions
2016-06-18 very rough buzzer tones added
    [RX4Diversity.ino]
2016-06-18 button and menu handling improvements
2016-06-18 module SPI code added
2017-02-19 Added project existing files not already under git
    [DC0030.SLDPRT, DC0030.STEP, Diode SMA.stp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]
2017-02-19 Added schematic and PCB 3D images.
2017-02-19 Added gerbers
2017-02-19 Added enclosure SW files.
    [Alu enclosure.SLDPRT, BODY_M14A_20.sldprt, BODY_MF06A.sldprt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]
2017-02-19 Added enclosure render
